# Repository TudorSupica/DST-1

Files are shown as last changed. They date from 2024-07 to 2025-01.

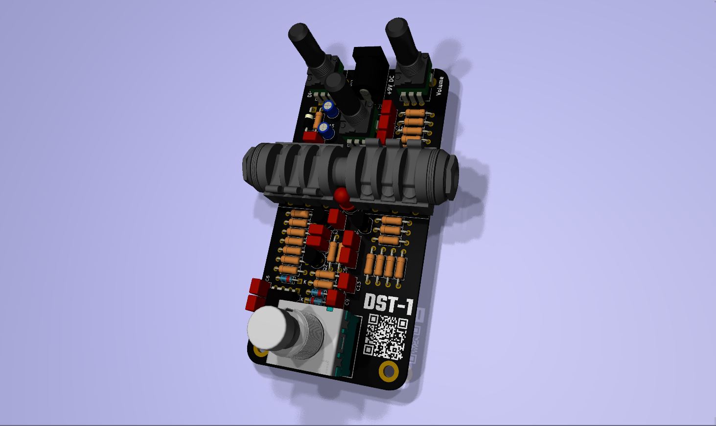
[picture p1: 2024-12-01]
PCB/3D/isometric.jpg

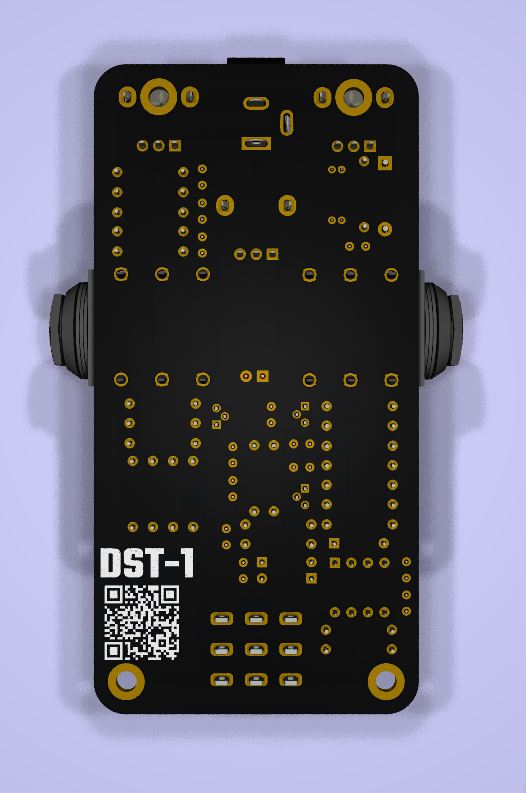
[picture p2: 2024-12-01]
PCB/3D/3D_back.jpg

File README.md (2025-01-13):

# The [BOSS DS-1](https://www.thomann.de/ro/boss_ds1_distortion.htm)

Maybe the most popular distortion pedal to ever hit the market. It's harsh attack and heavy distortion make it the perfect choice for genres like thrash and heavy metal.

# The [DST-1](https://github.com/TudorSupica/DST-1/)
isometric

The DST-1 is a copy of the DS-1's schematic, but modified in certain ways.
The original DS-1 used some relatively hard to find components, so i've swapped those out with some common components like the 2N3904 and the TL072.

This distorion pedal is intended to set the standard to me as to what "a good distortion pedal" sounds like. Usually distortion pedals are quite cheap and easy to build, but their sound comes down to the components used. Thus, I might swap out the TL072 for other op-amps aswell as the transistors. Good components make good pedals, but sometimes their cheapness and imperfections make the pedal unique. 

# [The Schematic](https://github.com/TudorSupica/DST-1/blob/main/Schematic/)
DST-1_Schematic
The schematic is quite cramped since I wanted it to fit all in a single unbroken signal line, from the input to the output. The +Vcc and -Vcc are supplied using a voltage divider between the positive and negative terminals of a 9v battery, also forming a vitual ground. To make sure I make the disctinction between the Gnd of the battery and the Gnd of the signal, I decided to rename signal's ground to +4,5v since it's the midway point between the +9v and the 0v of the battery.

The 3PDT switch didn't had any symbol in KiCAD's library so I made them myself, aswell as the footprint, using the datasheet for the switch. Feel free to copy use and share since resources should not be kept behind paywalls and such and anybody should have the right to use resources to create / recreate things.

# [The PCB](https://github.com/TudorSupica/DST-1/blob/main/PCB/)
I've yet to test the circuit, but the PCB is on it's way and will soonly arrive.

The PCB is made to fit in a Hammond 1590B aluminium enclosure, thus it's rather strict dimensions. I'm not quite sure if it'll fit tho since I've been too lazy to make the board's outline match the enclosure's lid, but I plan to do it... sometime in the future I hope ...

Here is the datasheet for the enclosure tho!



I also added some (4 to be precise) M3 mounting holes that are connected directly to 0v, thus being capable to ground the whole PCB if the user so desires.
The LED can be anything from red to UV, I used a 220 ohm resistor but it can be replaced with any kind of THT resistor to match the desired brightness/current need of an LED, if so desired.

I plan to power up the pedal using a 9v battery connected via a barrel jack, at the back of the board. 

To do:
- [x] Schematic
- [x] PCB design
- [ ] Integrate the pedal in an enclosure

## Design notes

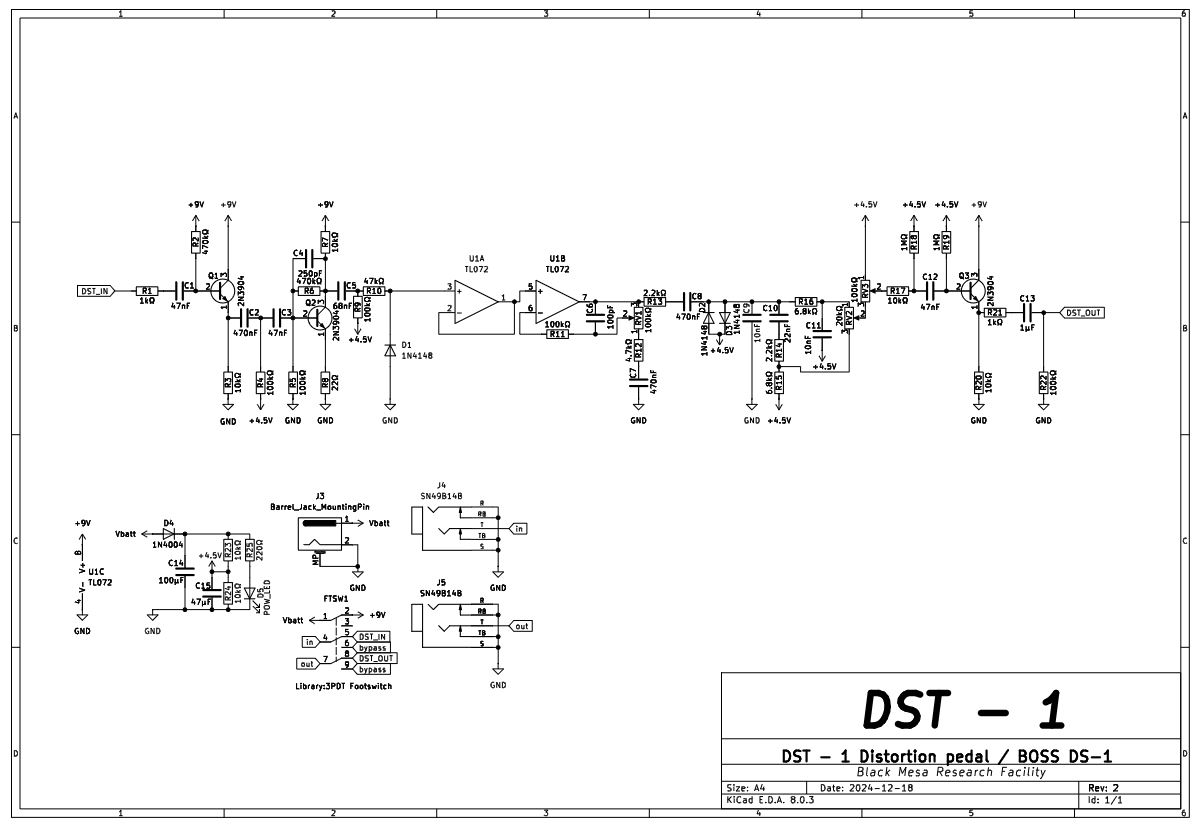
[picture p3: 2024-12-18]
Schematic/DST-1_Schematic.jpg

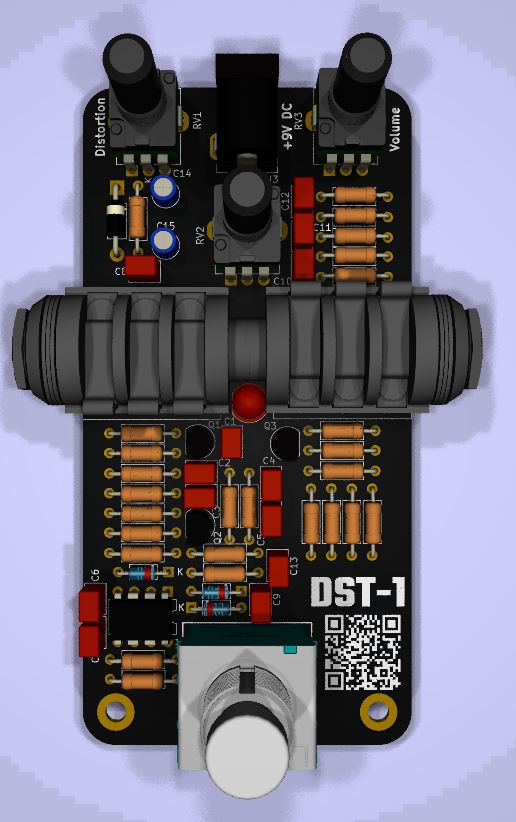
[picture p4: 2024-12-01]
PCB/3D/3D_front.jpg

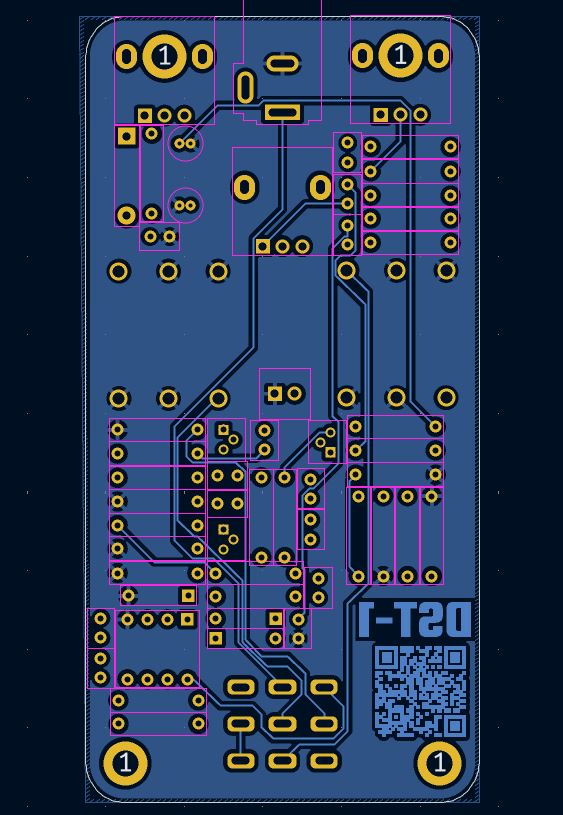
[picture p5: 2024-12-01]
PCB/2D/2D_back.jpg

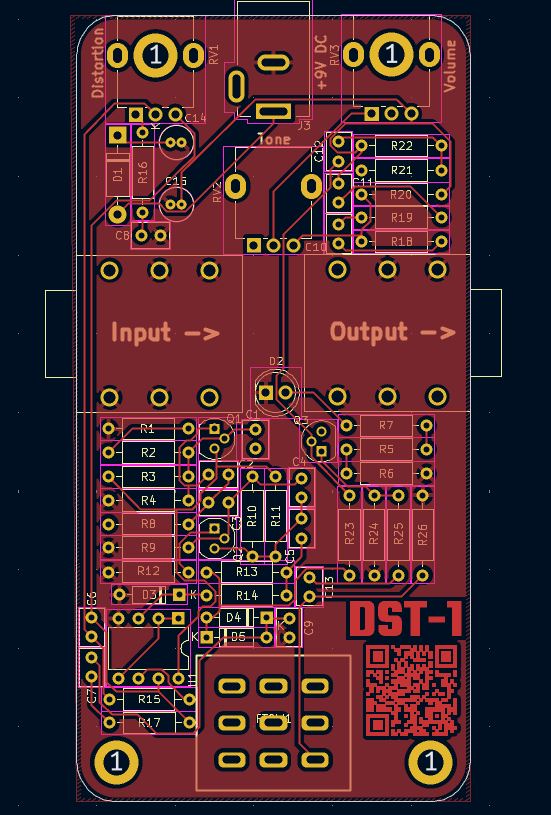
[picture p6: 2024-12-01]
PCB/2D/2D_front.jpg

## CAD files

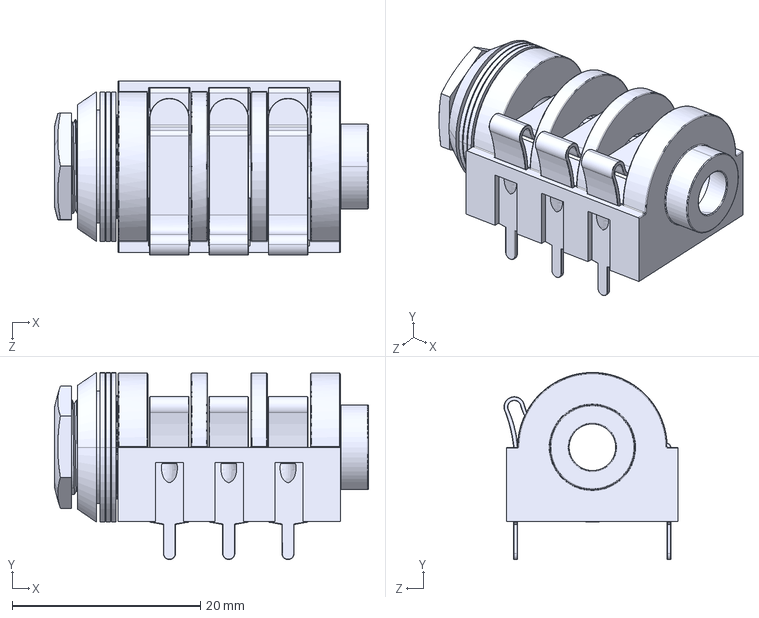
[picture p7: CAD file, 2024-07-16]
KiCAD files/PJ644C/PC644C.IGS
33.4 x 19.9 x 18.5 mm

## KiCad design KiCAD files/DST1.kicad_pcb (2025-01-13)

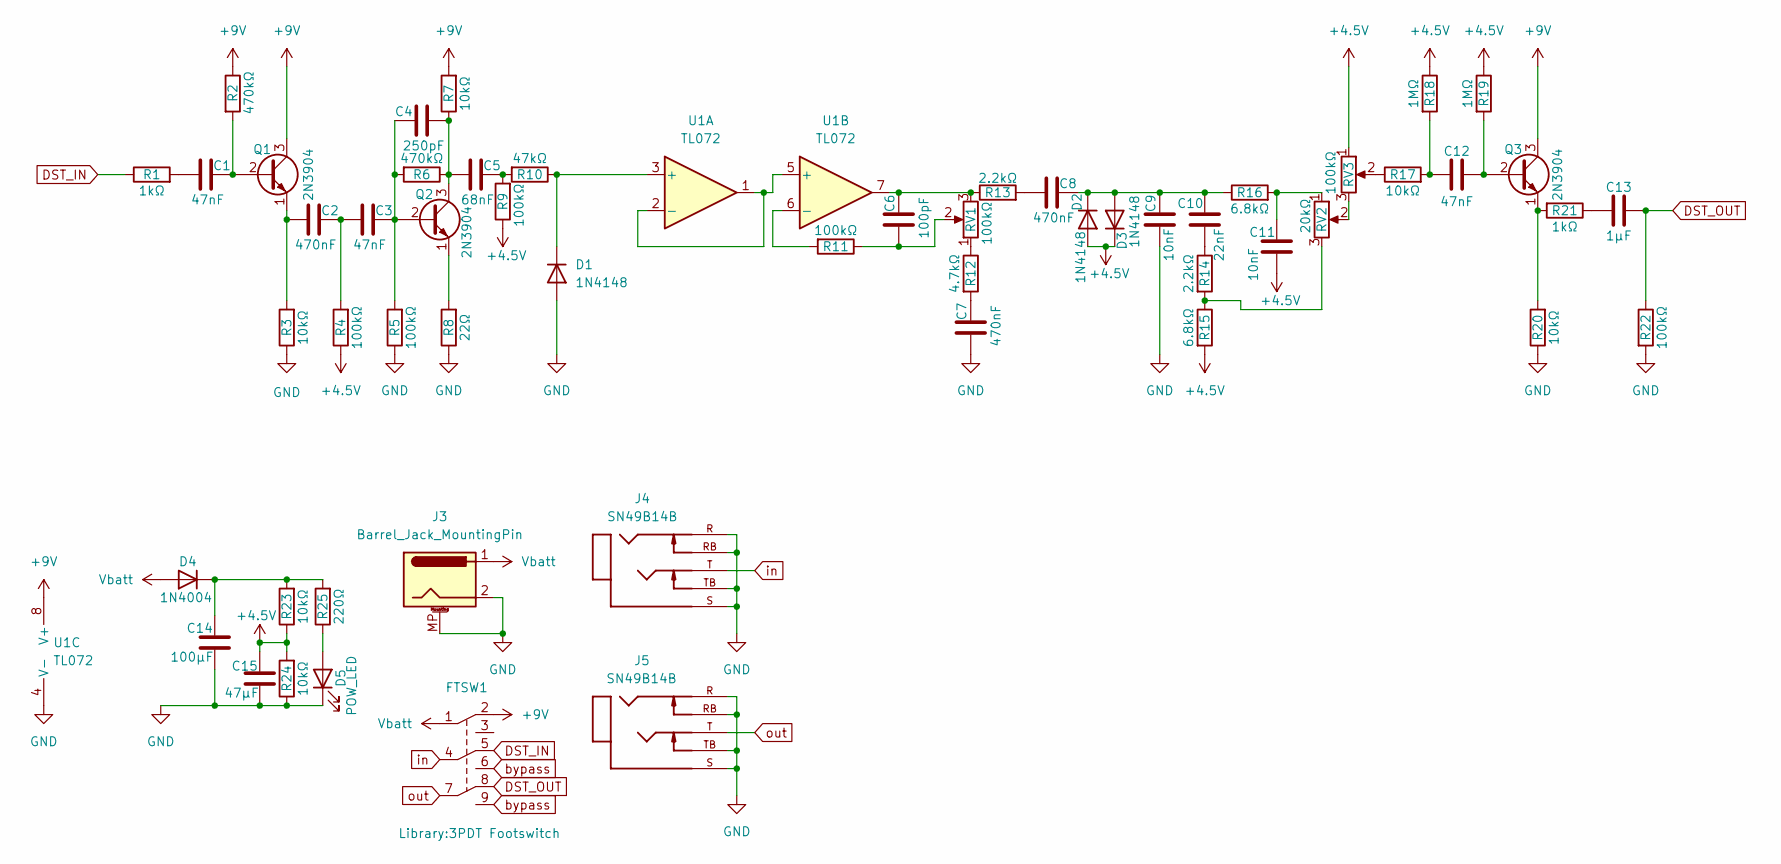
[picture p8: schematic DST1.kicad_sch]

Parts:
C1, C3, C12: 47nF; C_Rect_L4.6mm_W3.0mm_P2.50mm_MKS02_FKP02
C2, C7, C8: 470nF; C_Rect_L4.6mm_W3.0mm_P2.50mm_MKS02_FKP02
C4: 250pF; C_Rect_L4.6mm_W3.0mm_P2.50mm_MKS02_FKP02
C5: 68nF; C_Rect_L4.6mm_W3.0mm_P2.50mm_MKS02_FKP02
C6: 100pF; C_Rect_L4.6mm_W3.0mm_P2.50mm_MKS02_FKP02
C9, C11: 10nF; C_Rect_L4.6mm_W3.0mm_P2.50mm_MKS02_FKP02
C10: 22nF; C_Rect_L4.6mm_W3.0mm_P2.50mm_MKS02_FKP02
C13: 1µF; C_Rect_L4.6mm_W3.0mm_P2.50mm_MKS02_FKP02
C14: 100µF; C_Radial_D4.0mm_H5.0mm_P1.50mm
C15: 47µF; C_Radial_D4.0mm_H5.0mm_P1.50mm
D1, D2, D3: 1N4148; D_DO-35_SOD27_P7.62mm_Horizontal
D4: 1N4004; D_DO-41_SOD81_P10.16mm_Horizontal
D5: POW_LED; LED_D5.0mm
FTSW1: 3PDT Footswitch
J3: Barrel_Jack_MountingPin; BarrelJack_Kycon_KLDX-0202-xC_Horizontal
J4, J5: SN49B14B; PJ-644C; PARTREV F
Q1, Q2, Q3: 2N3904; TO-92
R1, R21: 1kΩ; R_Axial_DIN0207_L6.3mm_D2.5mm_P10.16mm_Horizontal
R2, R6: 470kΩ; R_Axial_DIN0207_L6.3mm_D2.5mm_P10.16mm_Horizontal
R3, R7, R17, R20, R23, R24: 10kΩ; R_Axial_DIN0207_L6.3mm_D2.5mm_P10.16mm_Horizontal
R4, R5, R9, R11, R22: 100kΩ; R_Axial_DIN0207_L6.3mm_D2.5mm_P10.16mm_Horizontal
R8: 22Ω; R_Axial_DIN0207_L6.3mm_D2.5mm_P10.16mm_Horizontal
R10: 47kΩ; R_Axial_DIN0207_L6.3mm_D2.5mm_P10.16mm_Horizontal
R12: 4.7kΩ; R_Axial_DIN0207_L6.3mm_D2.5mm_P10.16mm_Horizontal
R13, R14: 2.2kΩ; R_Axial_DIN0207_L6.3mm_D2.5mm_P10.16mm_Horizontal
R15, R16: 6.8kΩ; R_Axial_DIN0207_L6.3mm_D2.5mm_P10.16mm_Horizontal
R18, R19: 1MΩ; R_Axial_DIN0207_L6.3mm_D2.5mm_P10.16mm_Horizontal
R25: 220Ω; R_Axial_DIN0207_L6.3mm_D2.5mm_P10.16mm_Horizontal
RV1, RV3: 100kΩ; Potentiometer_Alpha_RD901F-40-00D_Single_Vertical
RV2: 20kΩ; Potentiometer_Alpha_RD901F-40-00D_Single_Vertical
U1: TL072; DIP-8_W7.62mm

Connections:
+4.5V: C11.1, C15.1, D2.2 (A), D3.1 (K), R4.1, R9.1, R15.2, R18.1, R19.1, R23.1, R24.2, RV3.1
+9V: FTSW1.2, Q1.3 (C), Q3.3 (C), R2.1, R7.2, U1.8 (V+)
DST_IN: FTSW1.5, R1.1
DST_OUT: C13.1, FTSW1.8, R22.1
GND: C7.1, C9.1, C14.2, C15.2, D1.2 (A), D5.1 (K), J3.2, J3.3, J3.MP (MountPin), J4.R, J4.RB, J4.S, J4.SB, J4.TB, J5.R, J5.RB, J5.S, J5.SB, J5.TB, R3.1, R5.1, R8.1, R20.1, R22.2, R24.1, U1.4 (V-)
unnamed: C1.1, R1.2
unnamed: C2.2, C3.1, R4.2
unnamed: C5.2, R9.2, R10.2
unnamed: C6.1, R11.1, RV1.2
unnamed: C6.2, R13.1, RV1.3, U1.7
unnamed: C7.2, R12.2
unnamed: C8.1, R13.2
unnamed: C10.1, R14.1
unnamed: C11.2, R16.2, RV2.1
unnamed: C12.2, R17.2, R18.2
unnamed: C13.2, R21.1
unnamed: D1.1 (K), R10.1, U1.3 (+)
unnamed: C8.2, C9.2, C10.2, D2.1 (K), D3.2 (A), R16.1
unnamed: C14.1, D4.1 (K), R23.2, R25.2
unnamed: D5.2 (A), R25.1
unnamed: C1.2, Q1.2 (B), R2.2
unnamed: C2.1, Q1.1 (E), R3.2
unnamed: C3.2, C4.1, Q2.2 (B), R5.2, R6.2
unnamed: C4.2, C5.1, Q2.3 (C), R6.1, R7.1
unnamed: Q2.1 (E), R8.2
unnamed: C12.1, Q3.2 (B), R19.2
unnamed: Q3.1 (E), R20.2, R21.2
unnamed: R12.1, RV1.1
unnamed: R14.2, R15.1, RV2.3
unnamed: R17.1, RV3.2
unnamed: RV2.2, RV3.3
unnamed: U1.1, U1.2 (-), U1.5 (+)
unnamed: R11.2, U1.6 (-)
Vbatt: D4.2 (A), FTSW1.1, J3.1
bypass: FTSW1.6, FTSW1.9
in: FTSW1.4, J4.T
out: FTSW1.7, J5.T

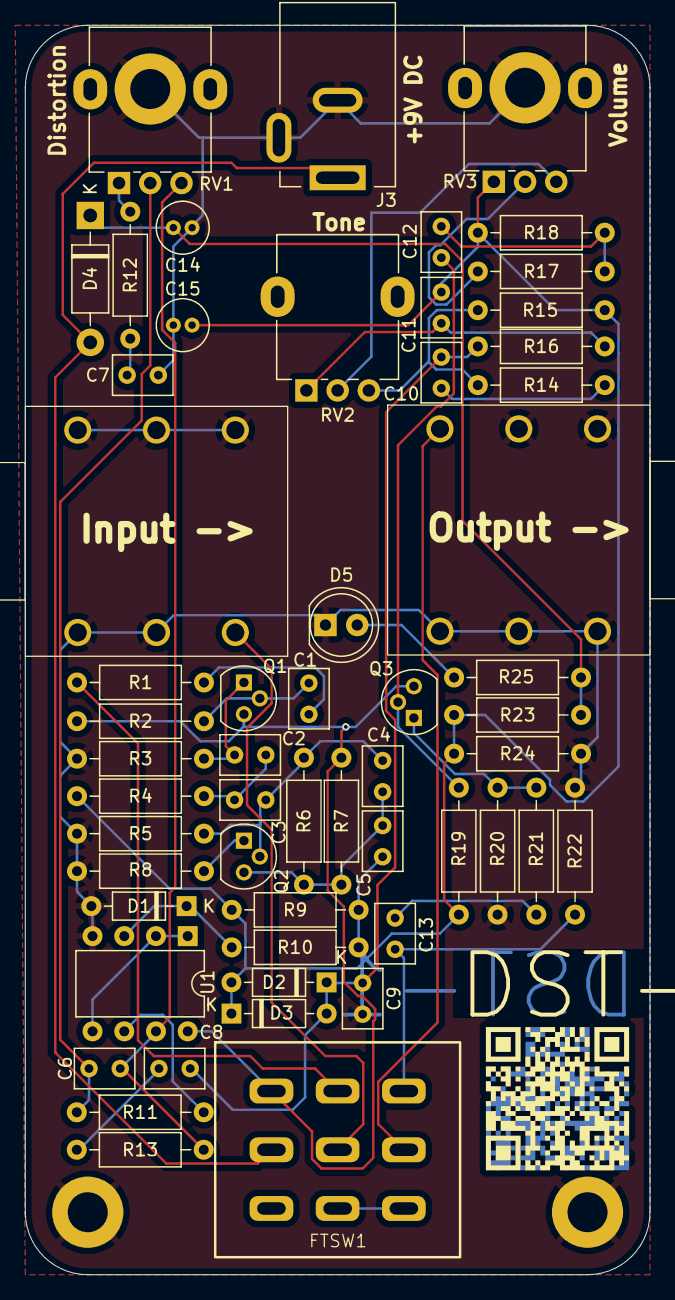
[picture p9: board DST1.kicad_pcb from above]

Board: 2 copper layers, 50.0 x 100.0 mm, 56 parts (0 on the bottom side), 37 nets.

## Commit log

2024-07-16 Added the PCB design and the schematic
    [DST1.kicad_pcb, DST1.kicad_sch, PC644C.IGS]
2024-07-16 Added a new 3D image of the PCB
2024-11-19 Update
    I updated the schematic and finished the PCB, might need to upload new photos tho.
    [DST1.kicad_pcb, DST1.kicad_sch]
2024-12-01 Update
    I updated the schematic PDF and the photo renders of the board
    [DST1-B_Cu.gbr, DST1-B_Mask.gbr, DST1-B_Paste.gbr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]
2024-12-18 Updated schematic and PCB
    I chose the wrong values for some resistors and capacitors, and so I had to update the schematic. I also wired the footswitch in a wrong manner and so I had to update the PCB.
    [DST1.kicad_pcb, DST1.kicad_sch]
2025-01-13 Updated the PCB
    [DST1.kicad_pcb]
2025-01-13 Added gerber files
    [DST1-B_Cu.gbr, DST1-B_Mask.gbr, DST1-B_Paste.gbr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]
